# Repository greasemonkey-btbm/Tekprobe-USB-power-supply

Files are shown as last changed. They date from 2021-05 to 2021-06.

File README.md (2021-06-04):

# Tekprobe USB power supply
 A USB power supply for the Tektronix Tekprobe interface
 https://btbm.ch/a-usb-power-supply-for-the-tekprobe-interface/

Original circuit posted by Jay_Diddy_B on the EEVBLOG forum
https://www.eevblog.com/forum/projects/tektronix-tekprobe-power-supply-for-agilent-rigol-and-other-oscilloscopes/

Contains the whole Altium Designer project and manufacturing files

Make sure you have read the Assembly details in the documents folder before you start making this project.

Enjoy!!!

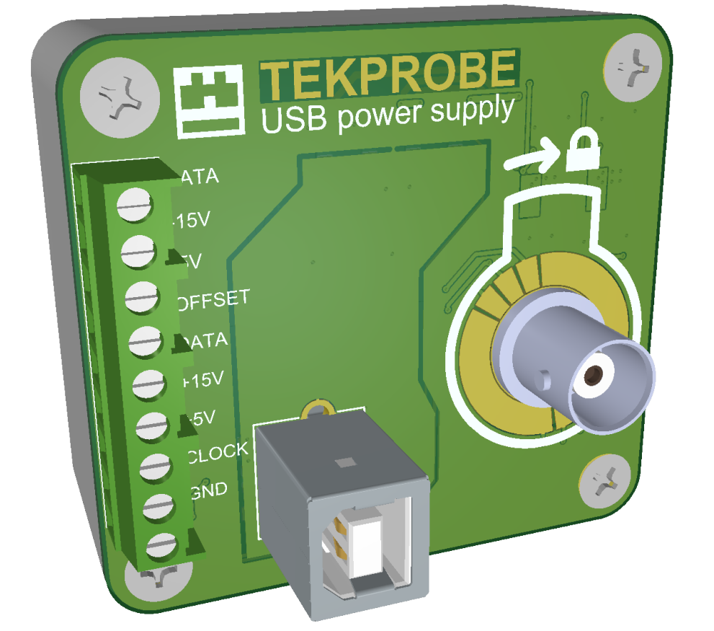
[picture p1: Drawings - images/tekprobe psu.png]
Tekprobe PSU


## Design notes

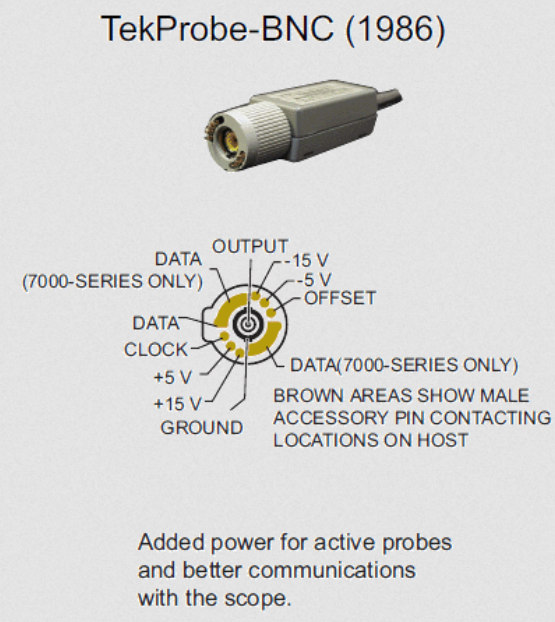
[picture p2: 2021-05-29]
Drawings - images/TekProbe20220Interface.PNG

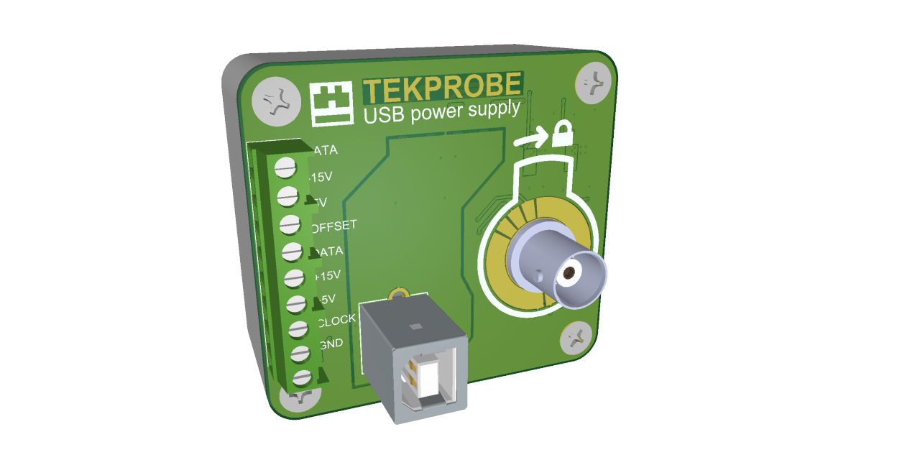
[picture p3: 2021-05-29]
Drawings - images/tekprobe psu l.png

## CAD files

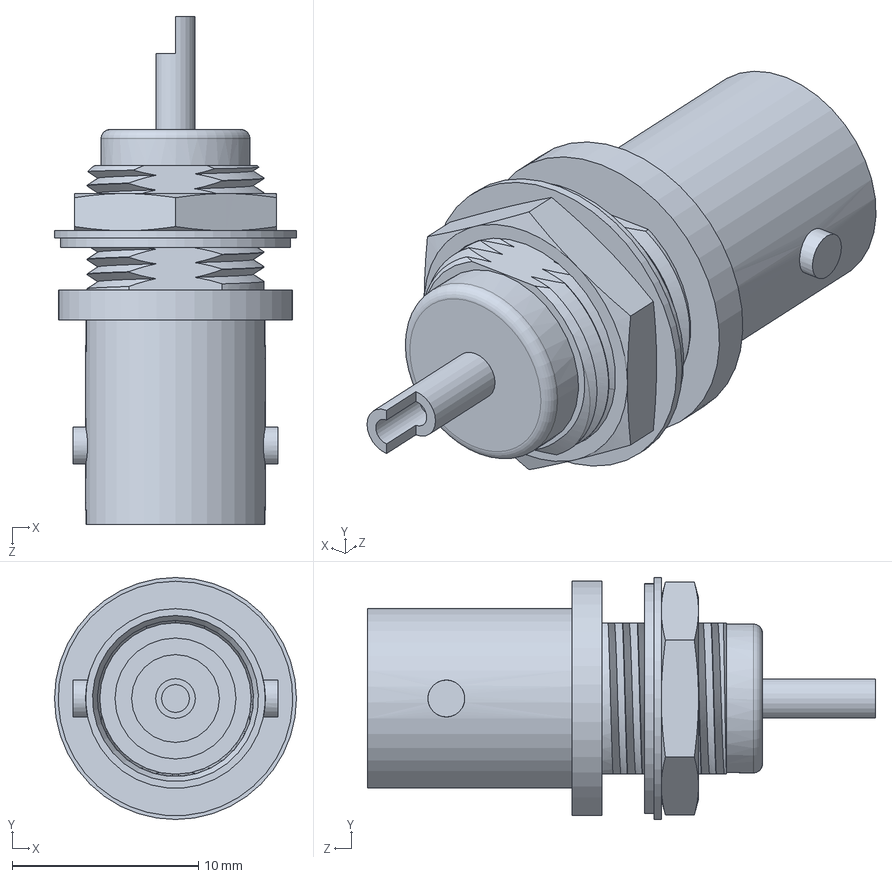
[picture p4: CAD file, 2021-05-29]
Drawings - images/Assem1.SLDASM
13.0 x 13.0 x 27.3 mm

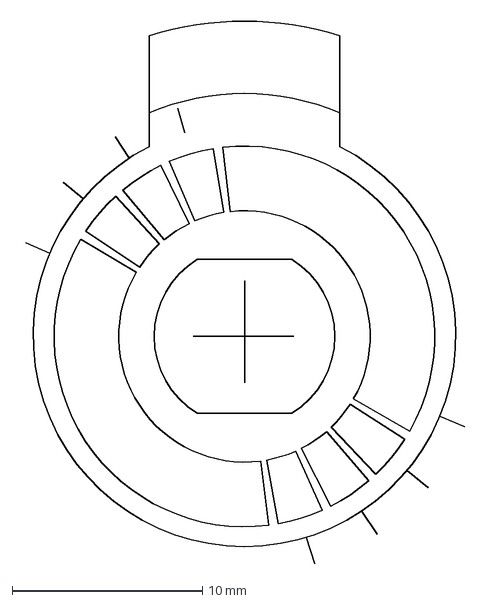
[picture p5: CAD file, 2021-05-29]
Drawings - images/tekprobe.dxf
24.0 x 28.8 mm

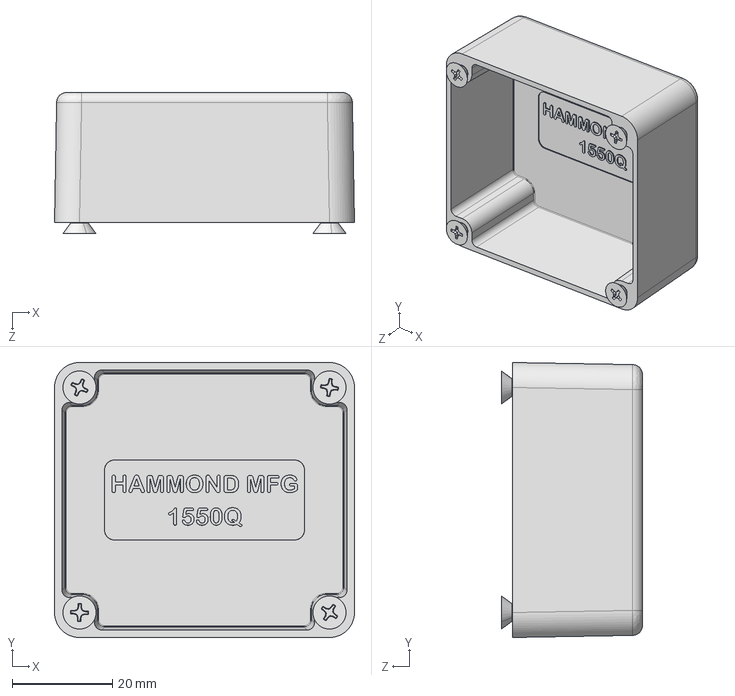
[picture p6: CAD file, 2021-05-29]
Drawings - images/1550Q.STEP
60.0 x 55.0 x 28.2 mm
1550Q BOX
SC1550 (screw M3.5-0.6X 12mm FH) x 4

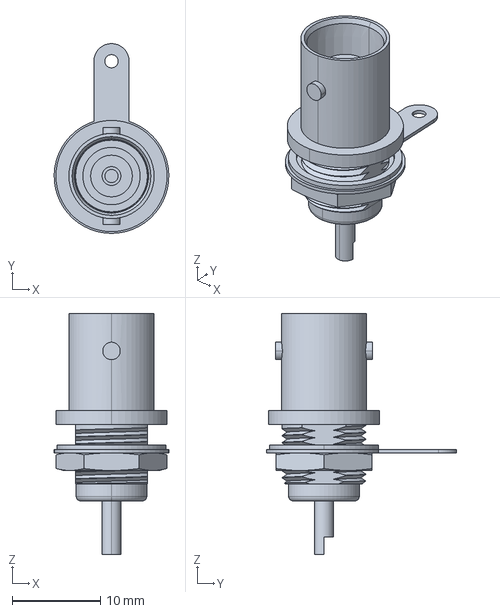
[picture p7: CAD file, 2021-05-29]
Drawings - images/c-5-1634523-1-b-3d.stp
13.0 x 21.5 x 27.3 mm

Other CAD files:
Drawings - images/bnc.STEP
Drawings - images/5-1634523-1.STEP
Drawings - images/1550Q BOX.sldprt
Drawings - images/SC1550 (screw M3.5-0.6X 12mm FH).sldprt
Drawings - images/1550Q.SLDASM
Drawings - images/1550Q.dxf
Drawings - images/1550Q.stp
Drawings - images/c-5-1634523-1-b-3d.SLDPRT

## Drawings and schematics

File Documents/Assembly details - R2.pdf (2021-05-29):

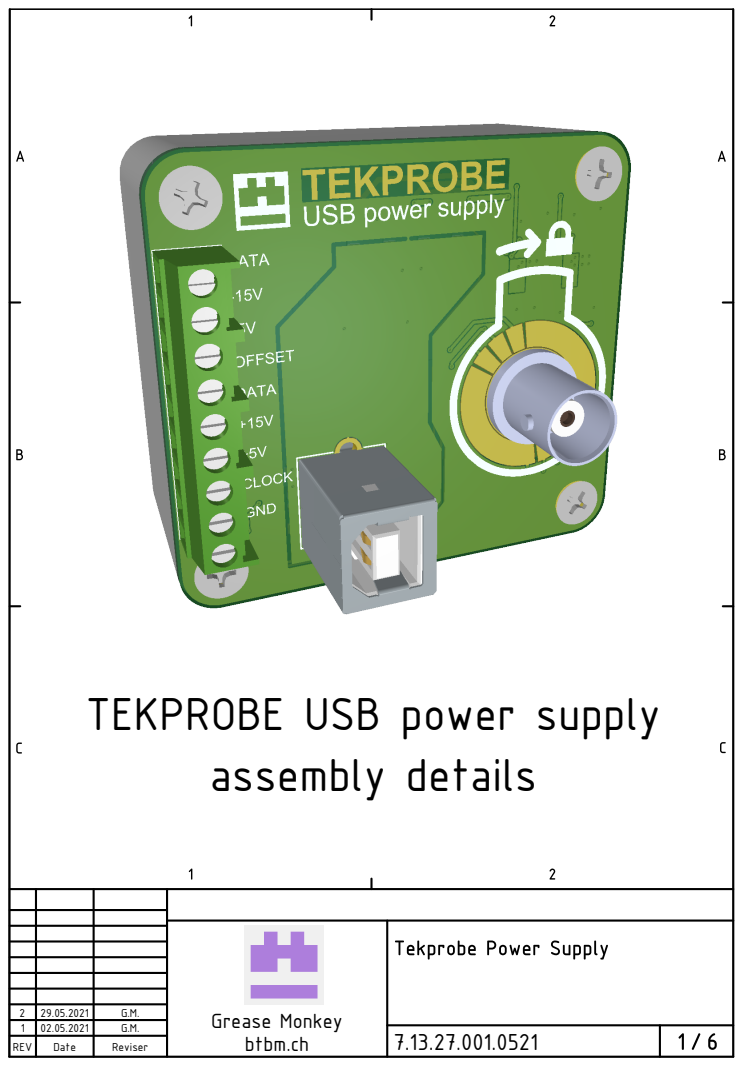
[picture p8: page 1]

TEKPROBE USB power supply
assembly details

2 | 29.05.2021 | G.M.
Grease Monkey btbm.ch
1 | 02.05.2021 | G.M.
REV | Date | Reviser

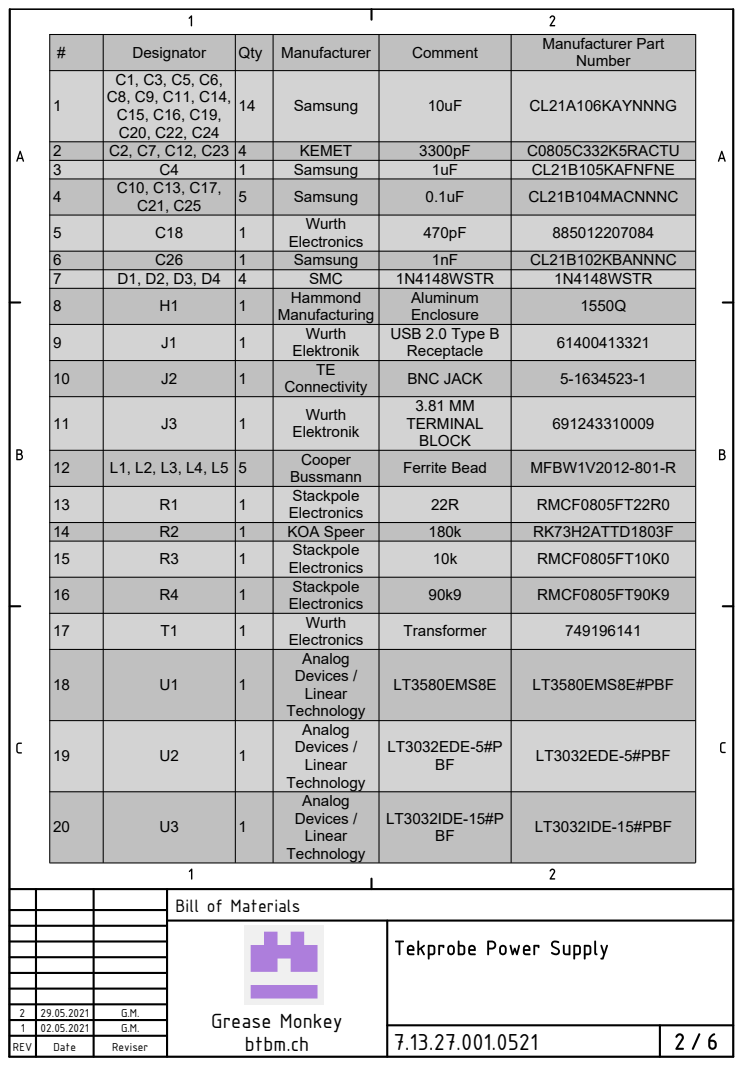
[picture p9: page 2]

# | Designator | Qty | Manufacturer | Comment | Manufacturer Part Number

1 | C1, C3, C5, C6, C8, C9, C11, C14, C15, C16, C19, C20, C22, C24 | 14 | Samsung | 10uF | CL21A106KAYNNNG

2 | C2, C7, C12, C23 | 4 | KEMET | 3300pF | C0805C332K5RACTU
3 | C4 | 1 | Samsung | 1uF | CL21B105KAFNFNE
4 | C10, C13, C17, C21, C25 | 5 | Samsung | 0.1uF | CL21B104MACNNNC

5 | C18 | 1 | Wurth Electronics | 470pF | 885012207084

6 | C26 | 1 | Samsung | 1nF | CL21B102KBANNNC
7 | D1, D2, D3, D4 | 4 | SMC | 1N4148WSTR | 1N4148WSTR
8 | H1 | 1 | Hammond Manufacturing | Aluminum Enclosure | 1550Q

9 | J1 | 1 | Wurth Elektronik | USB 2.0 Type B Receptacle | 61400413321

10 | J2 | 1 | TE Connectivity | BNC JACK | 5-1634523-1

11 | J3 | 1 | Wurth Elektronik | 3.81 MM TERMINAL BLOCK | 691243310009

12 | L1, L2, L3, L4, L5 | 5 | Cooper Bussmann | Ferrite Bead | MFBW1V2012-801-R

13 | R1 | 1 | Stackpole Electronics | 22R | RMCF0805FT22R0

14 | R2 | 1 | KOA Speer | 180k | RK73H2ATTD1803F
15 | R3 | 1 | Stackpole Electronics | 10k | RMCF0805FT10K0

16 | R4 | 1 | Stackpole Electronics | 90k9 | RMCF0805FT90K9

17 | T1 | 1 | Wurth Electronics | Transformer | 749196141

18 | U1 | 1 | Analog Devices / Linear Technology | LT3580EMS8E | LT3580EMS8E#PBF

19 | U2 | 1 | Analog Devices / Linear Technology | LT3032EDE-5#P BF | LT3032EDE-5#PBF

20 | U3 | 1 | Analog Devices / Linear Technology | LT3032IDE-15#P BF | LT3032IDE-15#PBF

### Top side

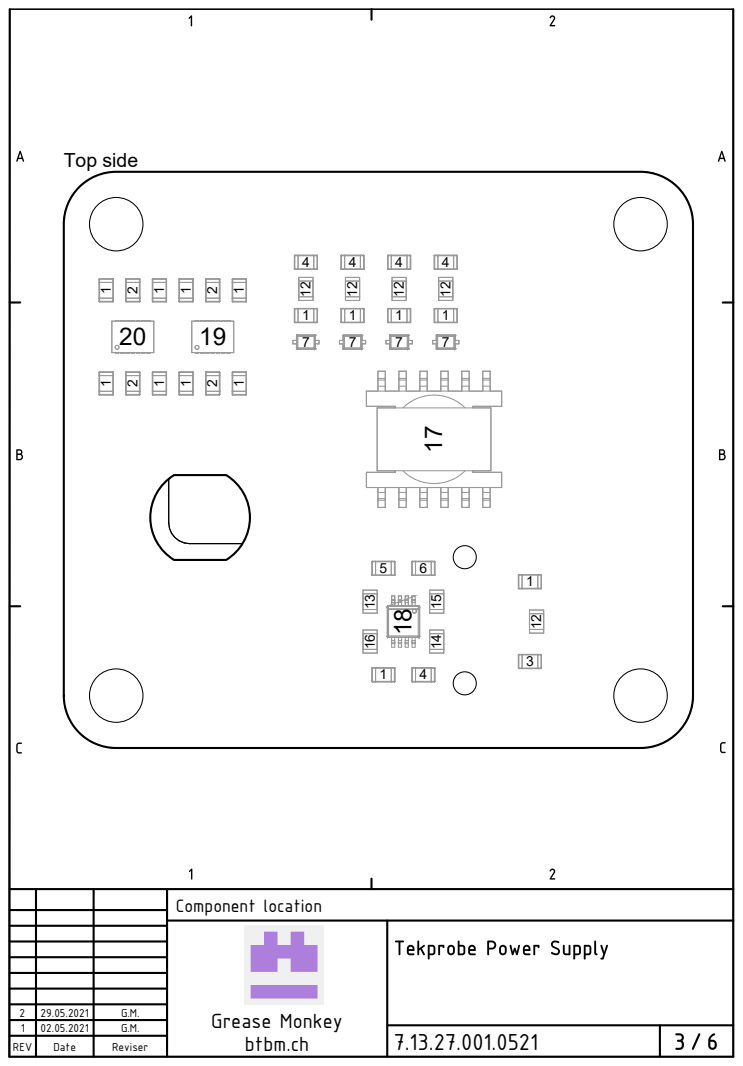
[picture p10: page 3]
Component location

### View from Left side (Scale 1:1)

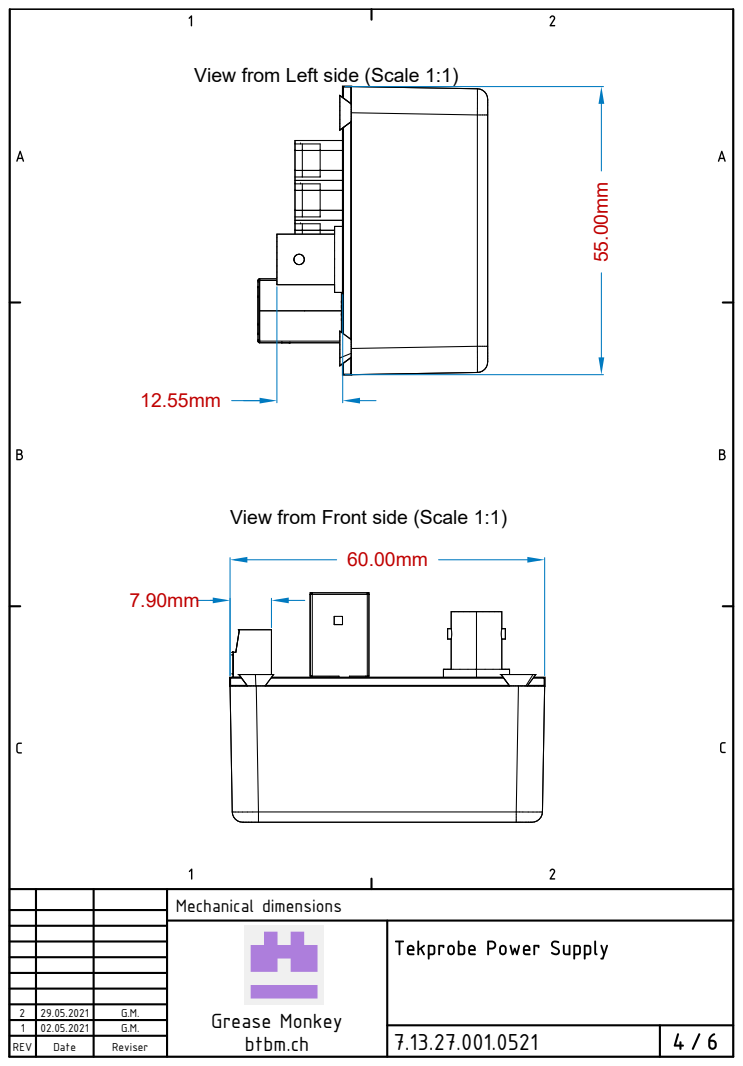
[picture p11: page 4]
Mechanical dimensions

View from Front side (Scale 1:1)

Rev.
1

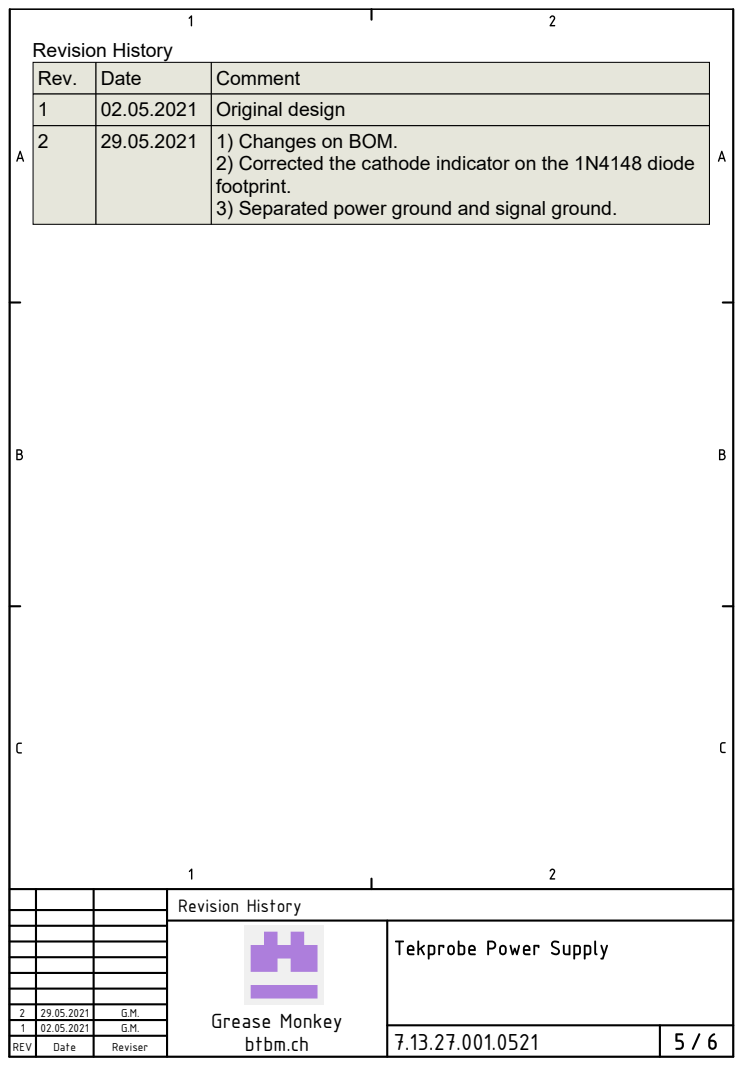
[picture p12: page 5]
Revision History; Date 02.05.2021 29.05.2021

Comment
Original design
1) Changes on BOM.
2) Corrected the cathode indicator on the 1N4148 diode
footprint.
3) Separated power ground and signal ground.

### View from Top side (Scale 1:1) DETAIL A (Scale 2:1)

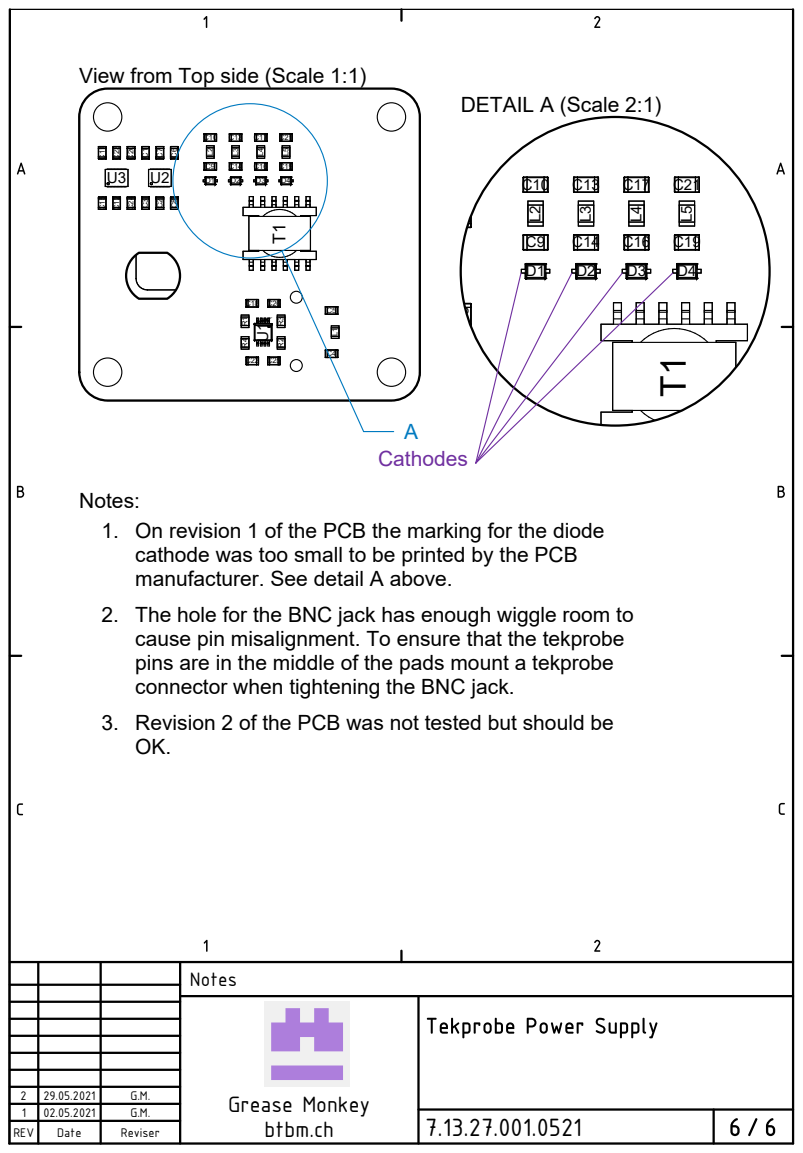
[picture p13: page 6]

Notes:
On revision 1 of the PCB the marking for the diode
cathode was too small to be printed by the PCB
manufacturer. See detail A above.
The hole for the BNC jack has enough wiggle room to
cause pin misalignment. To ensure that the tekprobe
pins are in the middle of the pads mount a tekprobe
connector when tightening the BNC jack.
Revision 2 of the PCB was not tested but should be

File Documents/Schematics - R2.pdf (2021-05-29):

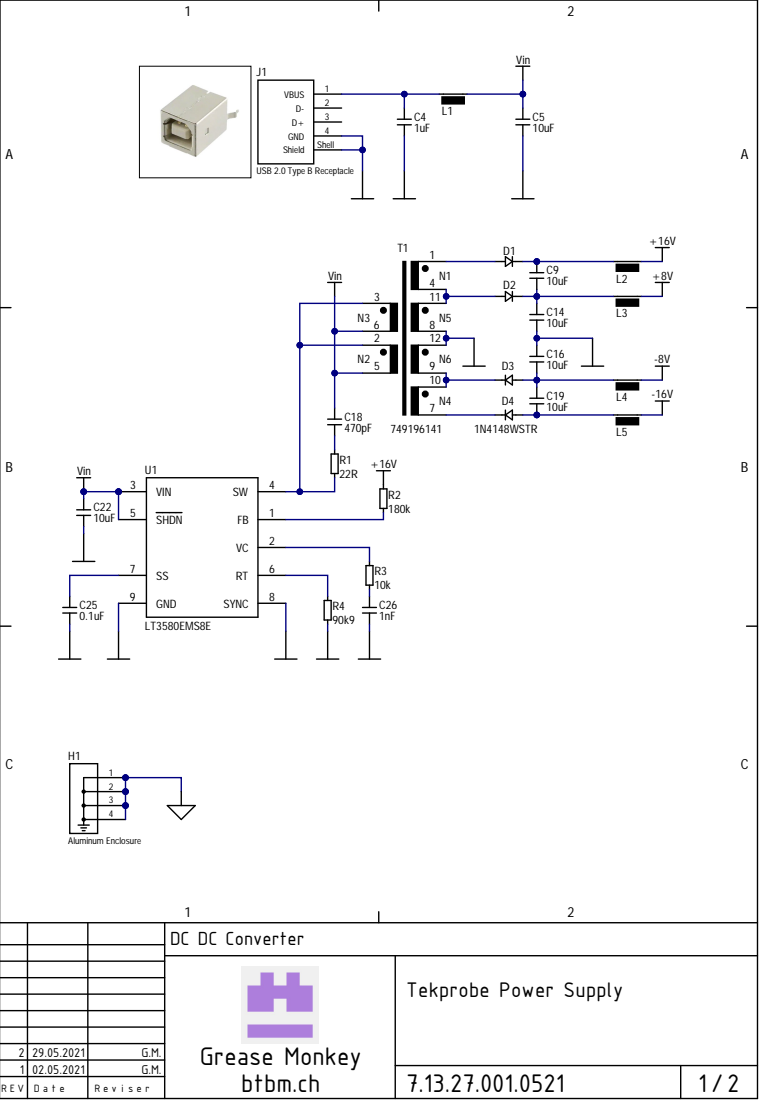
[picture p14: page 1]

N3
2 | 12
N2 | 5

DC DC Converter

Grease Monkey btbm.ch | Tekprobe Power Supply

2 | 29.05.2021 | G.M.
1 | 02.05.2021 | G.M.
REV | Date | Reviser

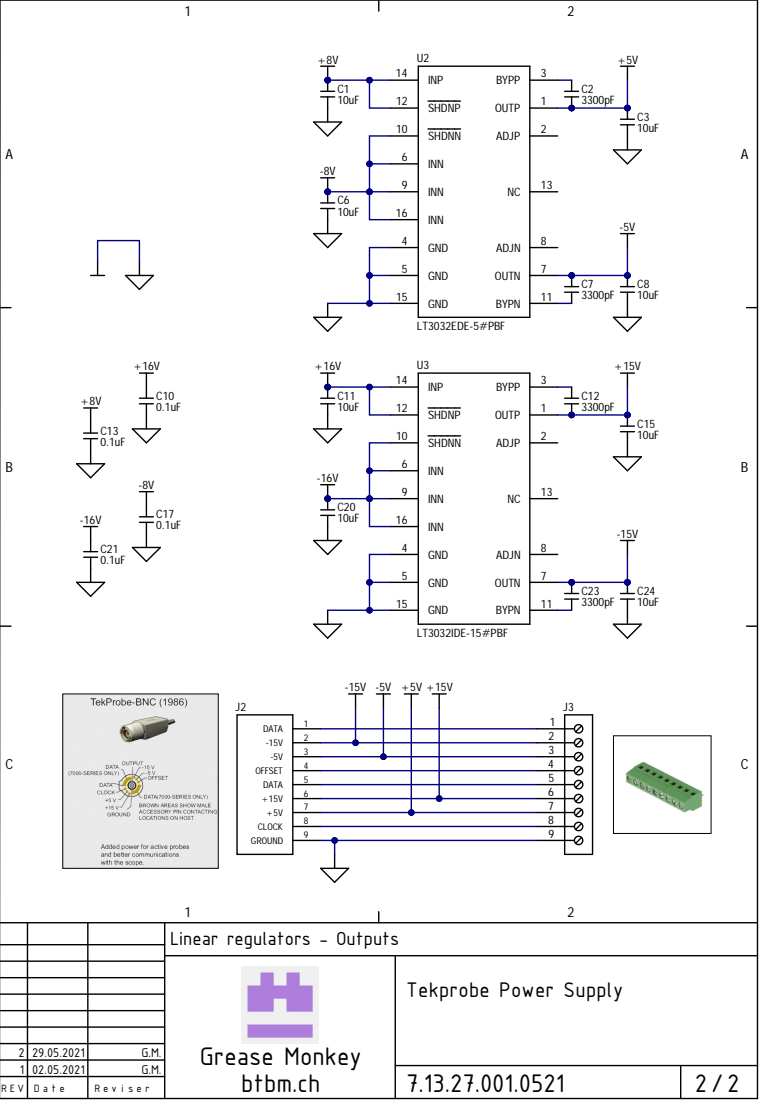
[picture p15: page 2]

Linear regulators - Outputs

Grease Monkey btbm.ch | Tekprobe Power Supply

2 | 29.05.2021 | G.M.
1 | 02.05.2021 | G.M.
REV | Date | Reviser
